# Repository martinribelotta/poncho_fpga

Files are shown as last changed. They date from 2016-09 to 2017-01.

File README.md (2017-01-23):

# FPGA Poncho para EDU CIAA

Poncho FPGA basado en la placa [Olimex iCE40HX1K-EVB](https://www.olimex.com/Products/FPGA/iCE40/iCE40HX1K-EVB/open-source-hardware)

> Licencia Apache 2.0 relicenciable a CIAA 1.0

## Caracteristicas
  - FPGA iCE40HX4K soportada por el proyecto IceStorm
  - 8-64MB de SDRAM
  - 64Mb SPI flash
  - Oscilador 50/100MHz on board
  - 52 I/O digitales 

## Lista de tareas
  - [x] Esqematico preeliminar
  - [x] Revision del esquematico
  - [x] Asignado de footprints
  - [x] Place and route
  - [x] Archivos de fabricacion
  - [x] Fabricación del PCB
  - [x] BOM (TBC)
  - [ ] Montaje y test

## Schematic
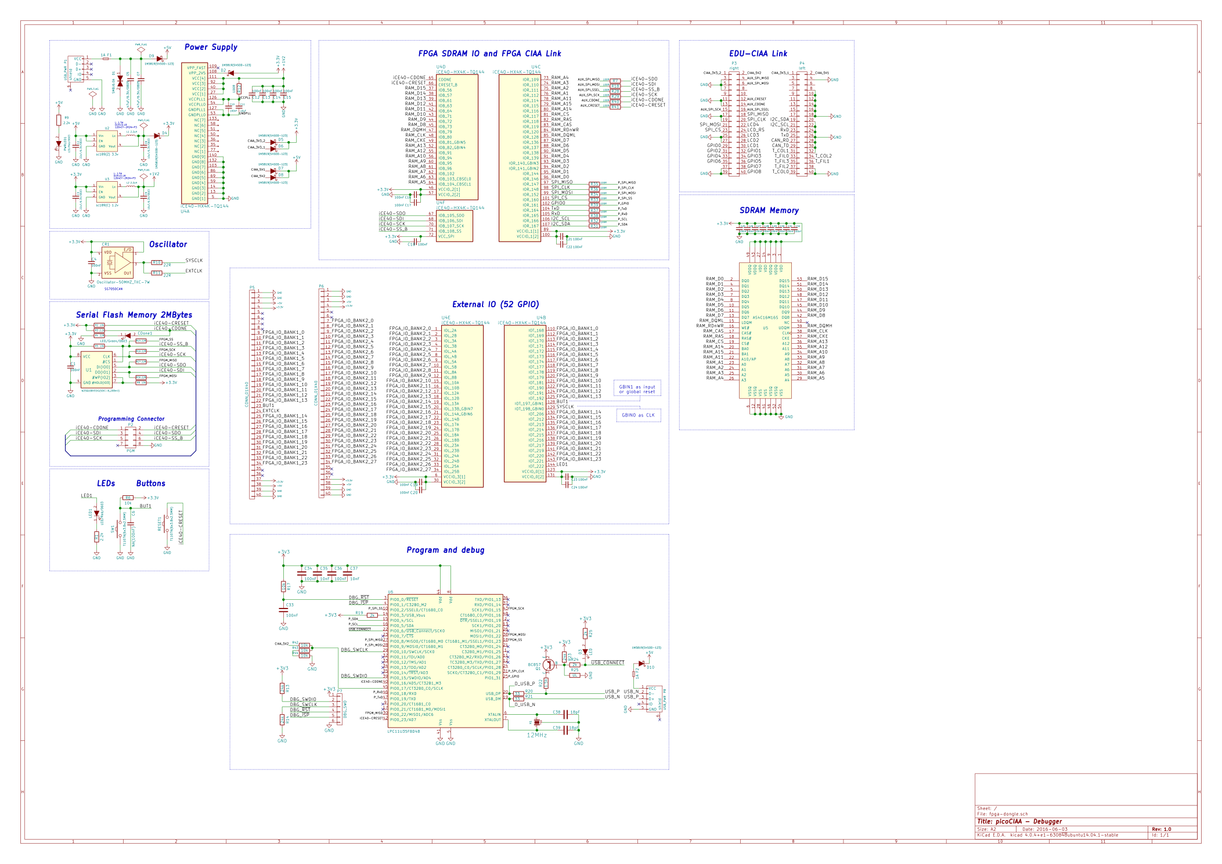
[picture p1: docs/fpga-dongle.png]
esquematico


## Board preview
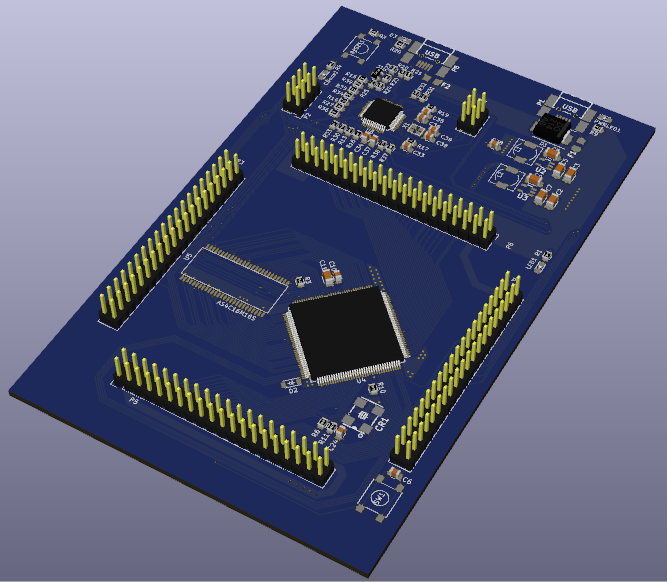
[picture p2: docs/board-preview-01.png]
preview1

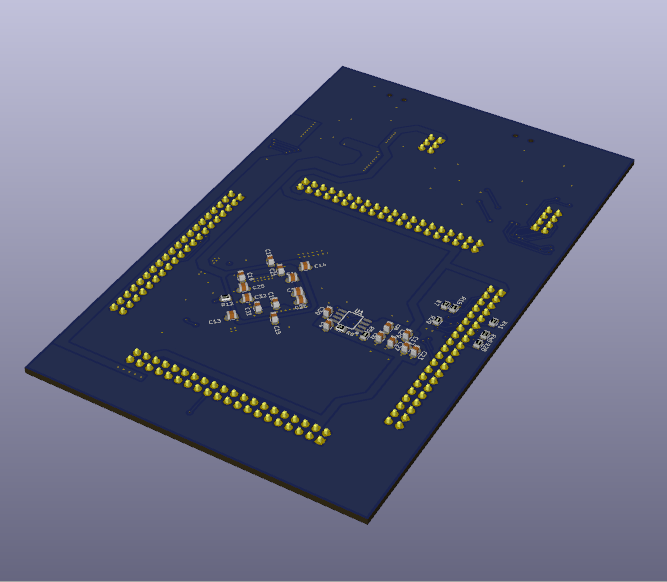
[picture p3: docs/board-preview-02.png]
preview2

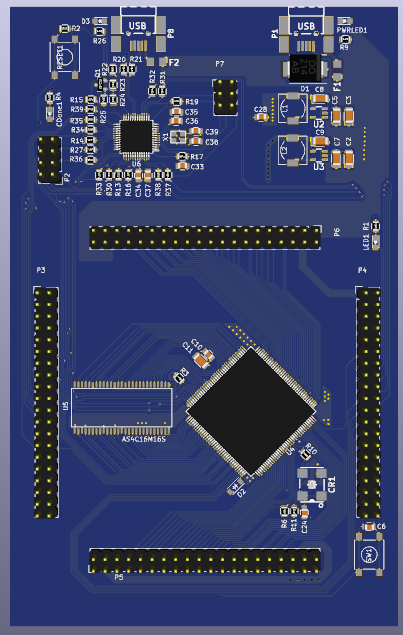
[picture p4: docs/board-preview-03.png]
preview3

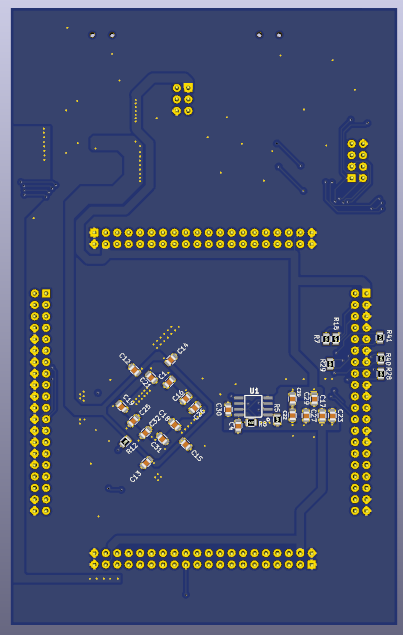
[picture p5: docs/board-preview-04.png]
preview4


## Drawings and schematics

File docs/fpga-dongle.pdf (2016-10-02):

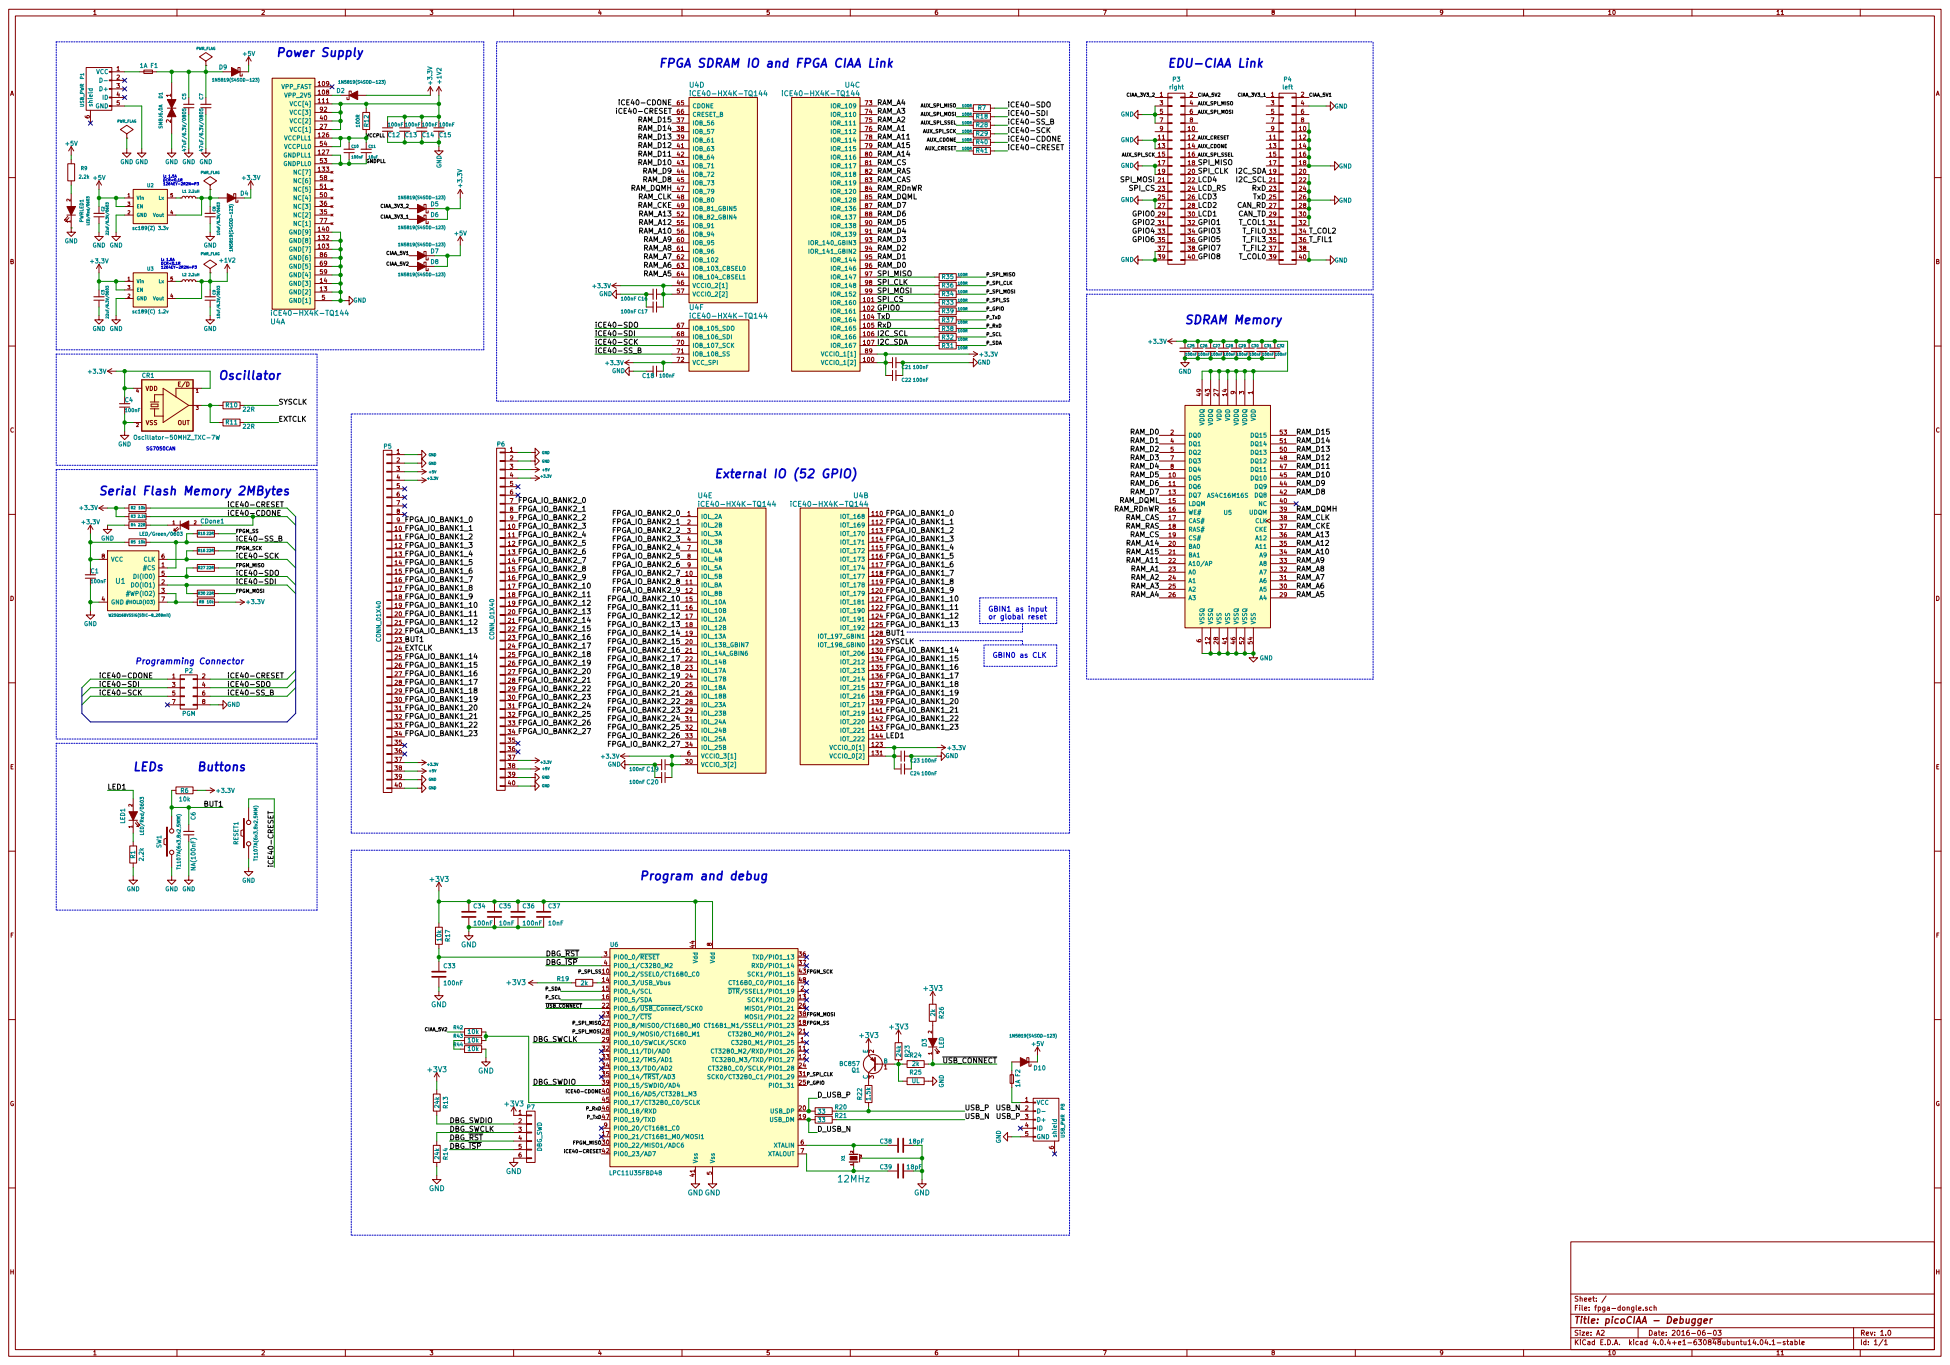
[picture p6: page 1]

File: fpga-dongle.sch Sheet: /
Id: 1/1 Title: picoCIAA - Debugger

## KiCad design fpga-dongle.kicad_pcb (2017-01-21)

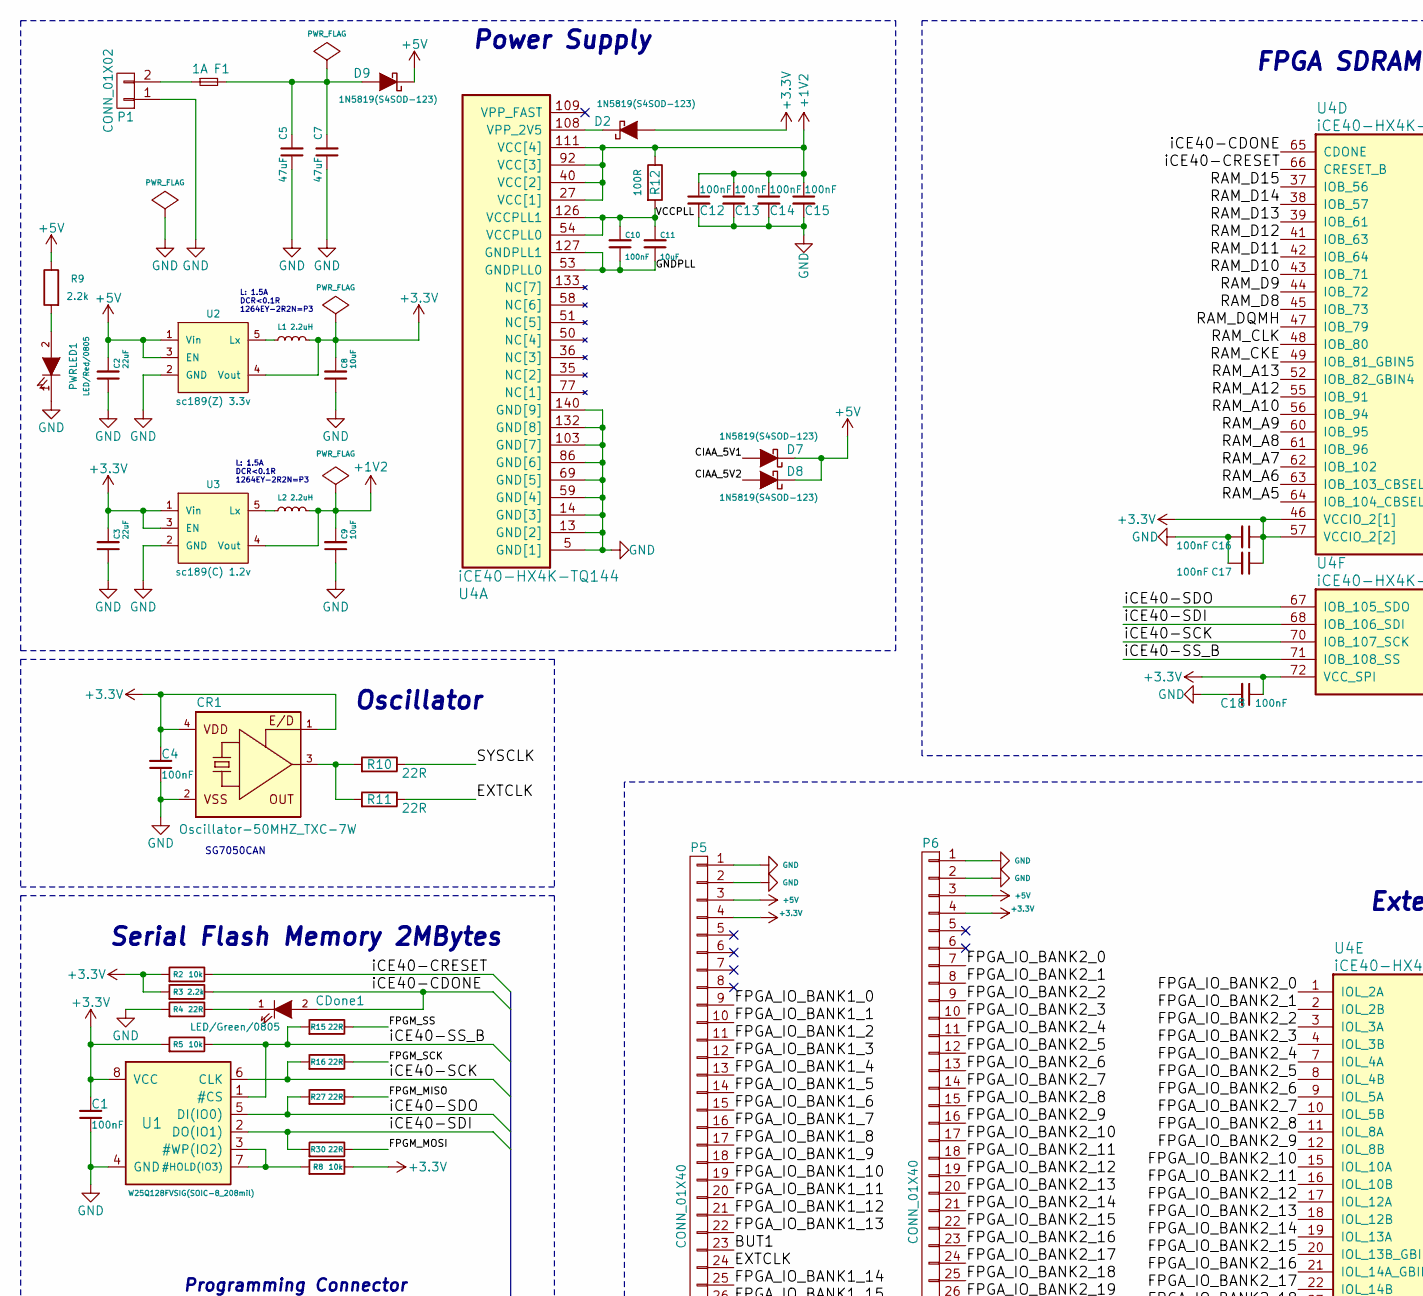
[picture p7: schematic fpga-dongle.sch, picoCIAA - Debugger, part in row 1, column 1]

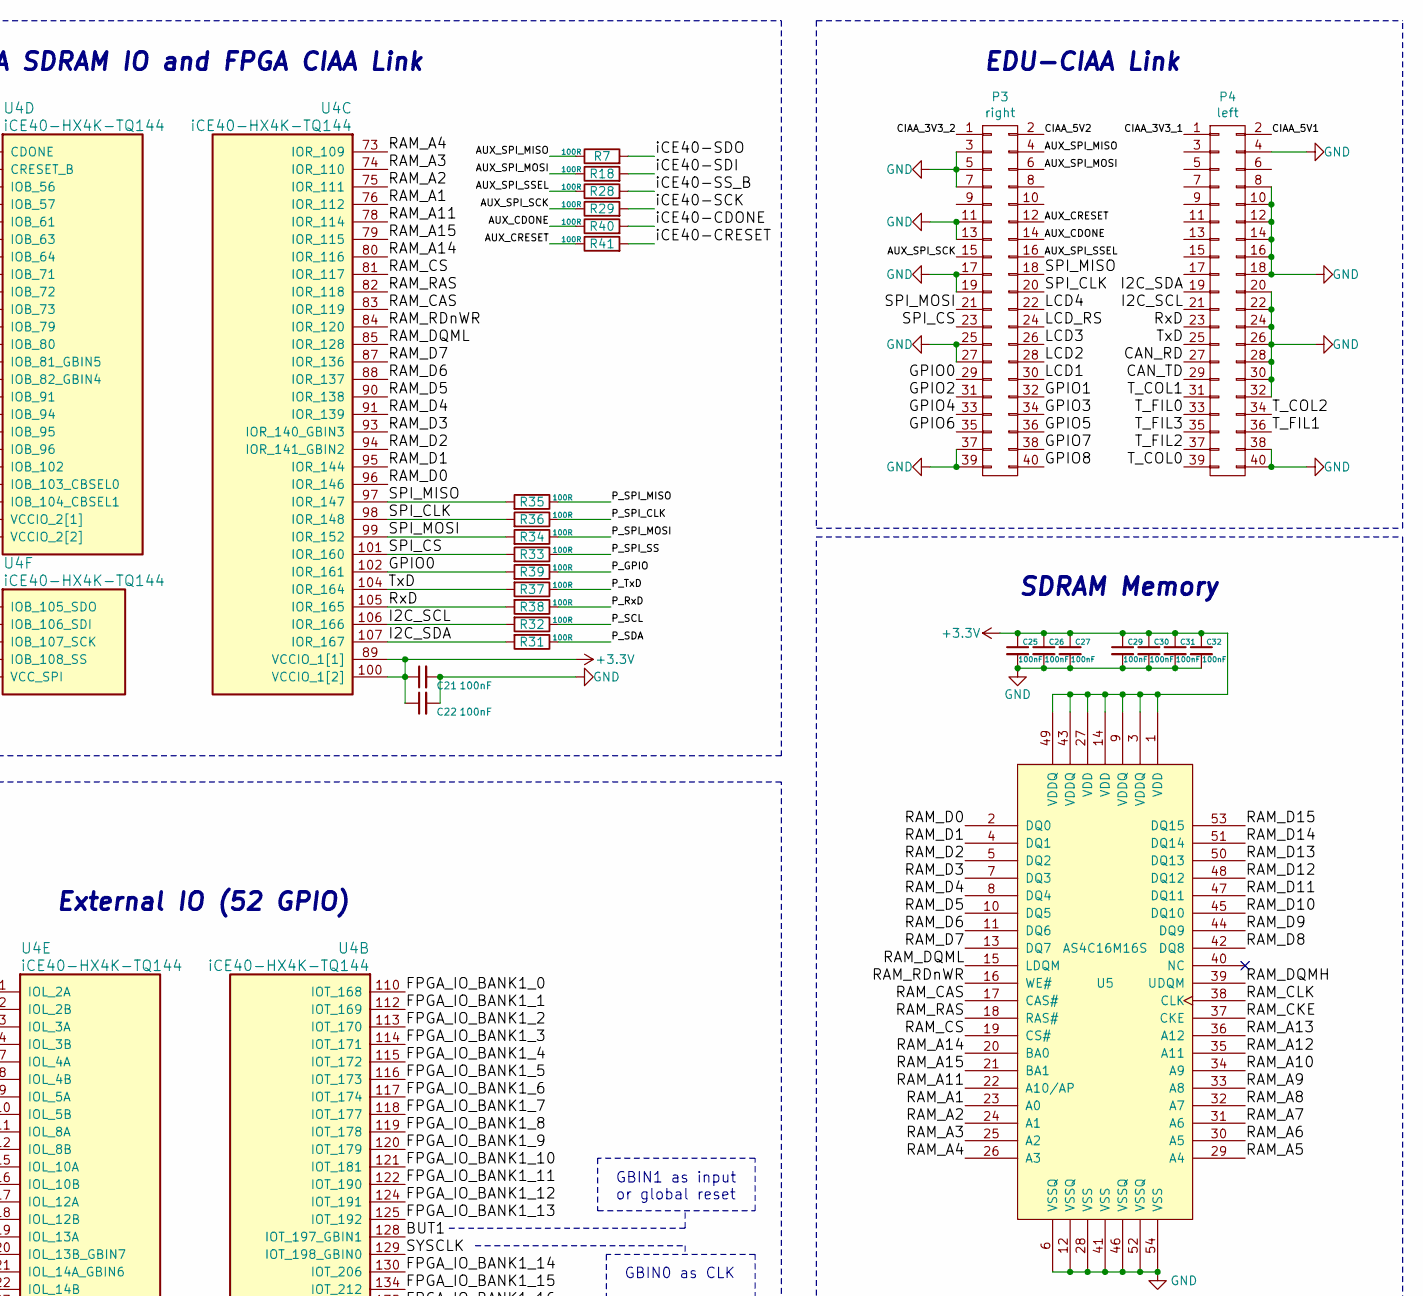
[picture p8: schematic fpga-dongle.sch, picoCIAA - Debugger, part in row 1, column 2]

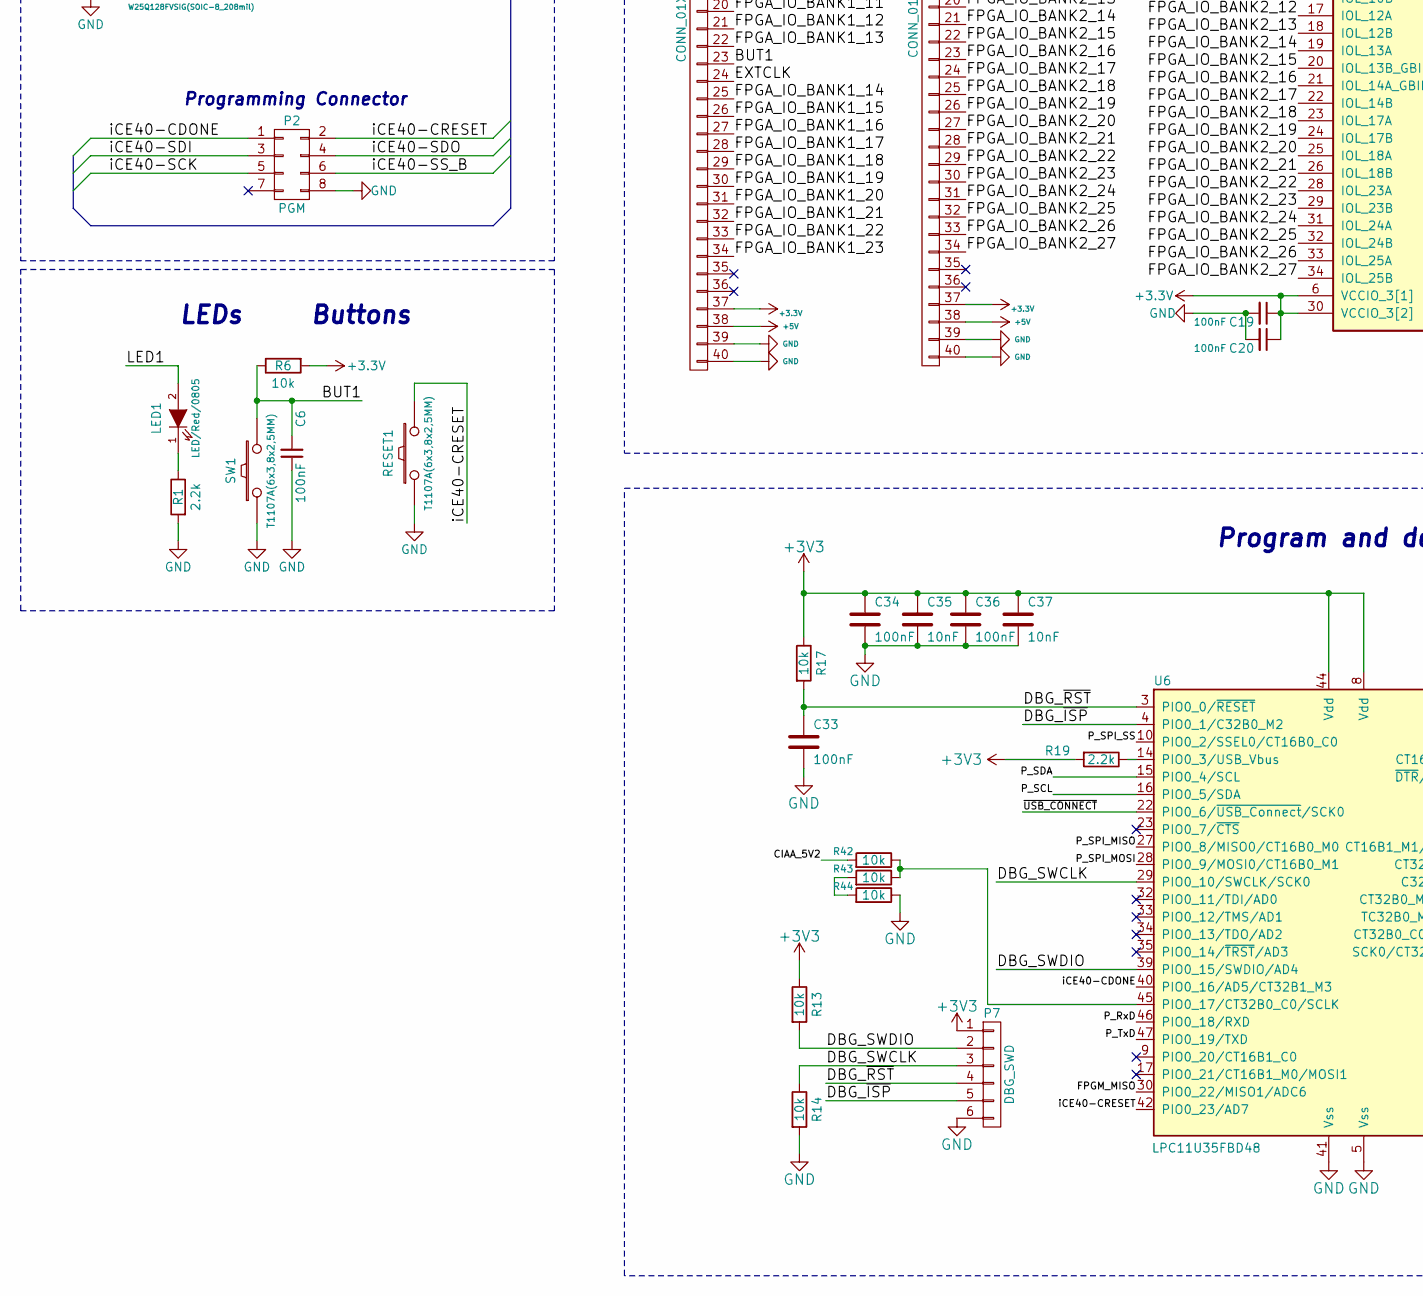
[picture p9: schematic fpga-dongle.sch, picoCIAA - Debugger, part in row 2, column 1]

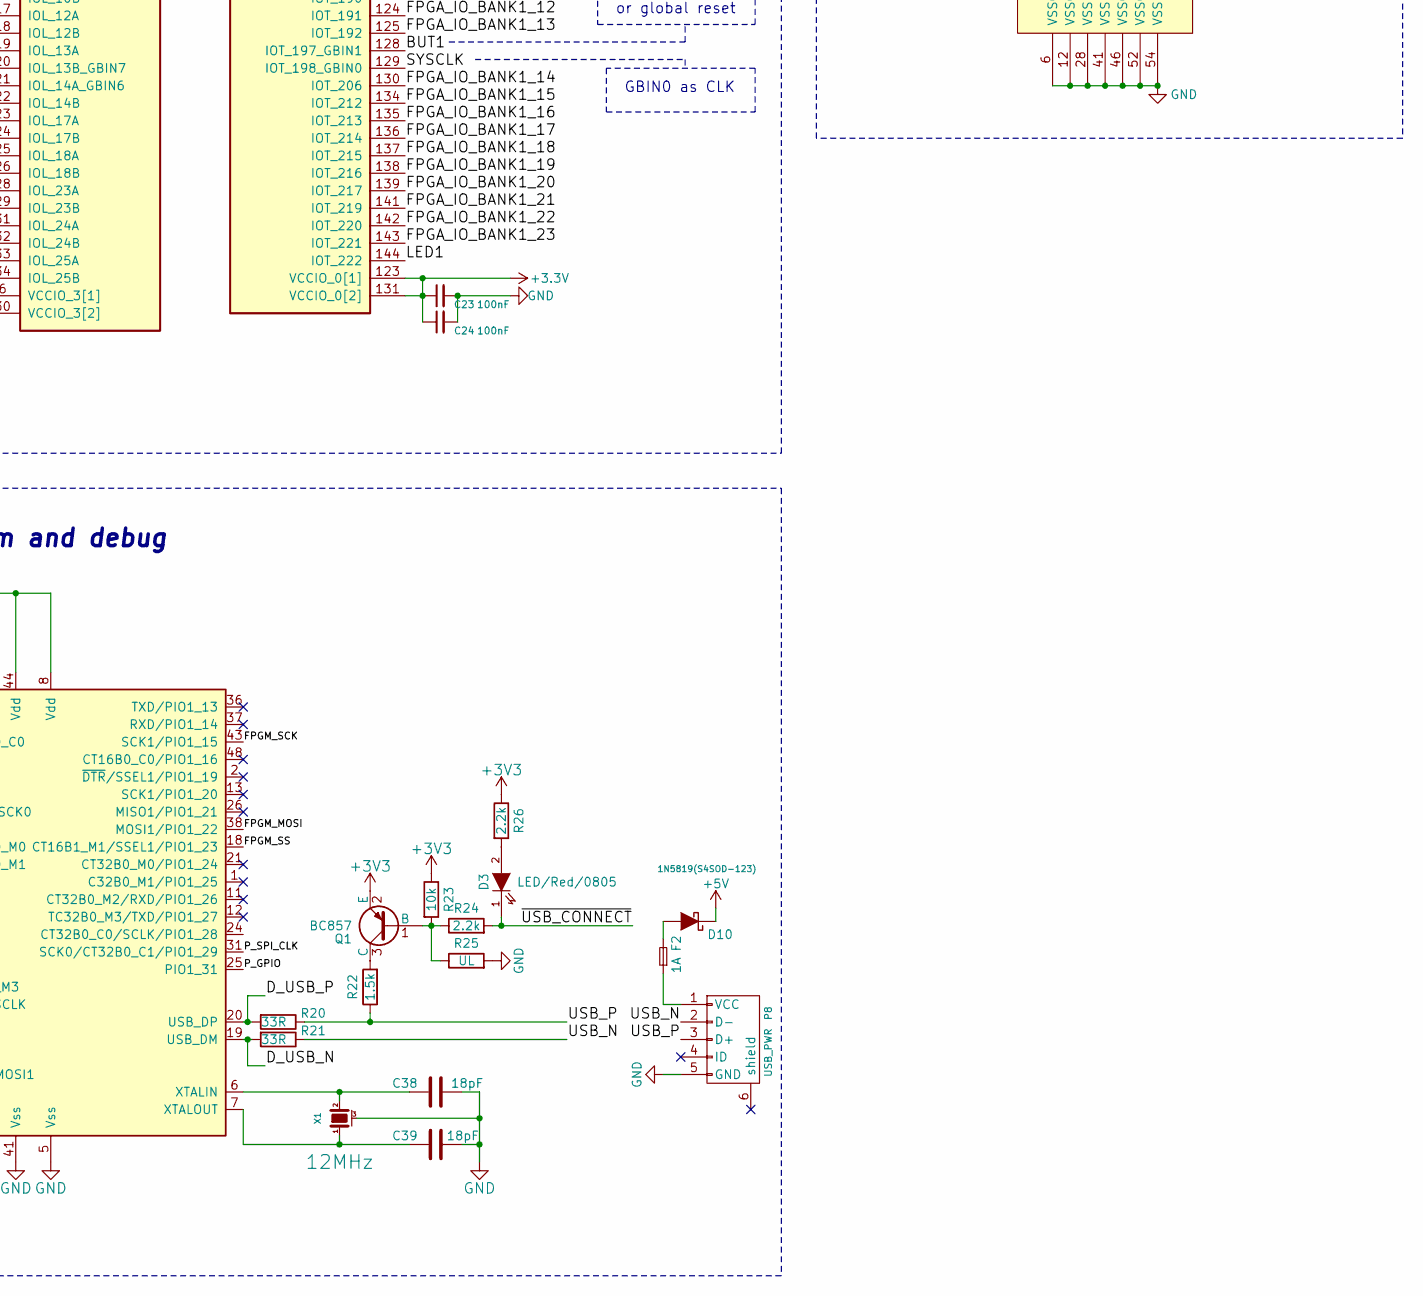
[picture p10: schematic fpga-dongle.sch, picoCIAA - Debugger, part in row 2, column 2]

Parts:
C1, C4, C6, C10, C12, C13, C14, C15, C16, C17, C18, C19, C20, C21, C22, C23, C24, C25, C26, C27, C29, C30, C31, C32, C33, C34, C36: 100nF; C_0805
C2, C3: 22uF; C_1206
C5, C7: 47uF; C_1206
C8, C9, C11: 10uF; C_1206
C35, C37: 10nF; C_0805
C38, C39: 18pF; C_0805
CDone1: LED/Green/0805; LED-0805
CR1: Oscillator-50MHZ_TXC-7W; Oscillator_7.0x5.0mm
D2, D7, D8, D9, D10: 1N5819(S4SOD-123); SOD-123
D3: LED/Red/0805; LED-0805
F1, F2: 1A; FUSE-1206
L1, L2: 2.2uH; Choke_SMD_6.3x6.3_H3
LED1: LED/Red/0805; LED-0805
P1: CONN_01X02; AK300-2
P2: PGM; Pin_Header_Straight_2x04
P3: right; Pin_Header_Straight_2x20
P4: left; Pin_Header_Straight_2x20
P5, P6: CONN_01X40; Pin_Header_Straight_2x20
P7: DBG_SWD; Pin_Header_Straight_2x03
P8: USB_PWR; USB_Mini-B-NOSILK
PWRLED1: LED/Red/0805; LED-0805
Q1: BC857; SOT-23
R1, R3, R9, R19, R24, R26: 2.2k; R_0805
R2, R5, R6, R8, R13, R14, R17, R23, R42, R43, R44: 10k; R_0805
R4, R10, R11, R15, R16, R27, R30: 22R; R_0805
R7, R12, R18, R28, R29, R31, R32, R33, R34, R35, R36, R37, R38, R39, R40, R41: 100R; R_0805
R20, R21: 33R; R_0805
R22: 1.5k; R_0805
R25: UL; R_0805
RESET1: T1107A(6x3,8x2,5MM); SW_SPST_PTS645
SW1: T1107A(6x3,8x2,5MM); SW_SPST_PTS645
U1: W25Q128FVSIG(SOIC-8_208mil); SOIC-8_208mil
U2: sc189(Z) 3.3v; SOT-23-5
U3: sc189(C) 1.2v; SOT-23-5
U4: iCE40-HX4K-TQ144; LQFP-144_20x20mm_Pitch0.5mm
U5: AS4C16M16S; TSOP_II_54
U6: LPC11U35FBD48; LQFP-48_7x7mm_Pitch0.5mm
X1: 12MHz; crystal_FA238-TSX3225; Digikey/Mouser 887-1831-1-ND

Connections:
+1V2: C9.2, C12.1, C13.1, C14.1, C15.1, L2.2, R12.1, U3.4 (Vout), U4.27 (VCC[1]), U4.40 (VCC[2]), U4.92 (VCC[3]), U4.111 (VCC[4])
+5V: C2.2, D7.1 (K), D8.1 (K), D9.1 (K), D10.1 (K), P5.3, P5.38, P6.3, P6.38, R9.1, U2.1 (Vin), U2.3 (EN)
/AUX_CDONE: P3.14, R40.1
/AUX_CRESET: P3.12, R41.1
/AUX_SPI_MISO: P3.4, R7.1
/AUX_SPI_MOSI: P3.6, R18.1
/AUX_SPI_SCK: P3.15, R29.1
/AUX_SPI_SSEL: P3.16, R28.1
/BUT1: C6.2, P5.23, R6.1, SW1.2, U4.128 (IOT_197_GBIN1)
/CAN_RD: P4.27
/CAN_TD: P4.29
/CIAA_3V3_1: P4.1
/CIAA_3V3_2: P3.1
/CIAA_5V1: D7.2 (A), P4.2
/CIAA_5V2: D8.2 (A), P3.2, R42.2
/DBG_SWCLK: P7.3, R14.1, U6.29 (PIO0_10/SWCLK/SCK0)
/DBG_SWDIO: P7.2, R13.2, U6.39 (PIO0_15/SWDIO/AD4)
/DBG_~ISP~: P7.5, U6.4 (PIO0_1/C32B0_M2)
/DBG_~RST~: C33.1, P7.4, R17.2, U6.3 (PIO0_0/~RESET)
/D_USB_N: R21.2, U6.19 (USB_DM)
/D_USB_P: R20.2, U6.20 (USB_DP)
/EXTCLK: P5.24, R11.1
/FPGA_IO_BANK1_0: P5.9, U4.110 (IOT_168)
/FPGA_IO_BANK1_1: P5.10, U4.112 (IOT_169)
/FPGA_IO_BANK1_2: P5.11, U4.113 (IOT_170)
/FPGA_IO_BANK1_3: P5.12, U4.114 (IOT_171)
/FPGA_IO_BANK1_4: P5.13, U4.115 (IOT_172)
/FPGA_IO_BANK1_5: P5.14, U4.116 (IOT_173)
/FPGA_IO_BANK1_6: P5.15, U4.117 (IOT_174)
/FPGA_IO_BANK1_7: P5.16, U4.118 (IOT_177)
/FPGA_IO_BANK1_8: P5.17, U4.119 (IOT_178)
/FPGA_IO_BANK1_9: P5.18, U4.120 (IOT_179)
/FPGA_IO_BANK1_10: P5.19, U4.121 (IOT_181)
/FPGA_IO_BANK1_11: P5.20, U4.122 (IOT_190)
/FPGA_IO_BANK1_12: P5.21, U4.124 (IOT_191)
/FPGA_IO_BANK1_13: P5.22, U4.125 (IOT_192)
/FPGA_IO_BANK1_14: P5.25, U4.130 (IOT_206)
/FPGA_IO_BANK1_15: P5.26, U4.134 (IOT_212)
/FPGA_IO_BANK1_16: P5.27, U4.135 (IOT_213)
/FPGA_IO_BANK1_17: P5.28, U4.136 (IOT_214)
/FPGA_IO_BANK1_18: P5.29, U4.137 (IOT_215)
/FPGA_IO_BANK1_19: P5.30, U4.138 (IOT_216)
/FPGA_IO_BANK1_20: P5.31, U4.139 (IOT_217)
/FPGA_IO_BANK1_21: P5.32, U4.141 (IOT_219)
/FPGA_IO_BANK1_22: P5.33, U4.142 (IOT_220)
/FPGA_IO_BANK1_23: P5.34, U4.143 (IOT_221)
/FPGA_IO_BANK2_0: P6.7, U4.1 (IOL_2A)
/FPGA_IO_BANK2_1: P6.8, U4.2 (IOL_2B)
/FPGA_IO_BANK2_2: P6.9, U4.3 (IOL_3A)
/FPGA_IO_BANK2_3: P6.10, U4.4 (IOL_3B)
/FPGA_IO_BANK2_4: P6.11, U4.7 (IOL_4A)
/FPGA_IO_BANK2_5: P6.12, U4.8 (IOL_4B)
/FPGA_IO_BANK2_6: P6.13, U4.9 (IOL_5A)
/FPGA_IO_BANK2_7: P6.14, U4.10 (IOL_5B)
/FPGA_IO_BANK2_8: P6.15, U4.11 (IOL_8A)
/FPGA_IO_BANK2_9: P6.16, U4.12 (IOL_8B)
/FPGA_IO_BANK2_10: P6.17, U4.15 (IOL_10A)
/FPGA_IO_BANK2_11: P6.18, U4.16 (IOL_10B)
/FPGA_IO_BANK2_12: P6.19, U4.17 (IOL_12A)
/FPGA_IO_BANK2_13: P6.20, U4.18 (IOL_12B)
/FPGA_IO_BANK2_14: P6.21, U4.19 (IOL_13A)
/FPGA_IO_BANK2_15: P6.22, U4.20 (IOL_13B_GBIN7)
/FPGA_IO_BANK2_16: P6.23, U4.21 (IOL_14A_GBIN6)
/FPGA_IO_BANK2_17: P6.24, U4.22 (IOL_14B)
/FPGA_IO_BANK2_18: P6.25, U4.23 (IOL_17A)
/FPGA_IO_BANK2_19: P6.26, U4.24 (IOL_17B)
/FPGA_IO_BANK2_20: P6.27, U4.25 (IOL_18A)
/FPGA_IO_BANK2_21: P6.28, U4.26 (IOL_18B)
/FPGA_IO_BANK2_22: P6.29, U4.28 (IOL_23A)
/FPGA_IO_BANK2_23: P6.30, U4.29 (IOL_23B)
/FPGA_IO_BANK2_24: P6.31, U4.31 (IOL_24A)
/FPGA_IO_BANK2_25: P6.32, U4.32 (IOL_24B)
/FPGA_IO_BANK2_26: P6.33, U4.33 (IOL_25A)
/FPGA_IO_BANK2_27: P6.34, U4.34 (IOL_25B)
/FPGM_MISO: R27.1, U6.30 (PIO0_22/MISO1/ADC6)
/FPGM_MOSI: R30.1, U6.38 (MOSI1/PIO1_22)
/FPGM_SCK: R16.1, U6.43 (SCK1/PIO1_15)
/FPGM_SS: R15.1, U6.18 (CT16B1_M1/SSEL1/PIO1_23)
/GNDPLL: C10.1, C11.1, U4.53 (GNDPLL0), U4.127 (GNDPLL1)
/GPIO0: P3.29, R39.2, U4.102 (IOR_161)
/GPIO1: P3.32
/GPIO2: P3.31
/GPIO3: P3.34
/GPIO4: P3.33
/GPIO5: P3.36
/GPIO6: P3.35
/GPIO7: P3.38
/GPIO8: P3.40
/I2C_SCL: P4.21, R32.2, U4.106 (IOR_166)
/I2C_SDA: P4.19, R31.2, U4.107 (IOR_167)
/LCD1: P3.30
/LCD2: P3.28
/LCD3: P3.26
/LCD4: P3.22
/LCD_RS: P3.24
/LED1: LED1.2 (A), U4.144 (IOT_222)
/P_GPIO: R39.1, U6.25 (PIO1_31)
/P_RxD: R38.1, U6.46 (PIO0_18/RXD)
/P_SCL: R32.1, U6.16 (PIO0_5/SDA)
/P_SDA: R31.1, U6.15 (PIO0_4/SCL)
/P_SPI_CLK: R36.1, U6.31 (SCK0/CT32B0_C1/PIO1_29)
/P_SPI_MISO: R35.1, U6.27 (PIO0_8/MISO0/CT16B0_M0)
/P_SPI_MOSI: R34.1, U6.28 (PIO0_9/MOSI0/CT16B0_M1)
/P_SPI_SS: R33.1, U6.10 (PIO0_2/SSEL0/CT16B0_C0)
/P_TxD: R37.1, U6.47 (PIO0_19/TXD)
/RAM_A1: U4.76 (IOR_112), U5.23 (A0)
/RAM_A2: U4.75 (IOR_111), U5.24 (A1)
/RAM_A3: U4.74 (IOR_110), U5.25 (A2)
/RAM_A4: U4.73 (IOR_109), U5.26 (A3)
/RAM_A5: U4.64 (IOB_104_CBSEL1), U5.29 (A4)
/RAM_A6: U4.63 (IOB_103_CBSEL0), U5.30 (A5)
/RAM_A7: U4.62 (IOB_102), U5.31 (A6)
/RAM_A8: U4.61 (IOB_96), U5.32 (A7)
/RAM_A9: U4.60 (IOB_95), U5.33 (A8)
/RAM_A10: U4.56 (IOB_94), U5.34 (A9)
/RAM_A11: U4.78 (IOR_114), U5.22 (A10/AP)
/RAM_A12: U4.55 (IOB_91), U5.35 (A11)
/RAM_A13: U4.52 (IOB_82_GBIN4), U5.36 (A12)
/RAM_A14: U4.80 (IOR_116), U5.20 (BA0)
/RAM_A15: U4.79 (IOR_115), U5.21 (BA1)
/RAM_CAS: U4.83 (IOR_119), U5.17 (CAS#)
/RAM_CKE: U4.49 (IOB_81_GBIN5), U5.37 (CKE)
/RAM_CLK: U4.48 (IOB_80), U5.38 (CLK)
/RAM_CS: U4.81 (IOR_117), U5.19 (CS#)
/RAM_D0: U4.96 (IOR_146), U5.2 (DQ0)
/RAM_D1: U4.95 (IOR_144), U5.4 (DQ1)
/RAM_D2: U4.94 (IOR_141_GBIN2), U5.5 (DQ2)
/RAM_D3: U4.93 (IOR_140_GBIN3), U5.7 (DQ3)
/RAM_D4: U4.91 (IOR_139), U5.8 (DQ4)
/RAM_D5: U4.90 (IOR_138), U5.10 (DQ5)
/RAM_D6: U4.88 (IOR_137), U5.11 (DQ6)
/RAM_D7: U4.87 (IOR_136), U5.13 (DQ7)
/RAM_D8: U4.45 (IOB_73), U5.42 (DQ8)
/RAM_D9: U4.44 (IOB_72), U5.44 (DQ9)
/RAM_D10: U4.43 (IOB_71), U5.45 (DQ10)
/RAM_D11: U4.42 (IOB_64), U5.47 (DQ11)
/RAM_D12: U4.41 (IOB_63), U5.48 (DQ12)
/RAM_D13: U4.39 (IOB_61), U5.50 (DQ13)
/RAM_D14: U4.38 (IOB_57), U5.51 (DQ14)
/RAM_D15: U4.37 (IOB_56), U5.53 (DQ15)
/RAM_DQMH: U4.47 (IOB_79), U5.39 (UDQM)
/RAM_DQML: U4.85 (IOR_128), U5.15 (LDQM)
/RAM_RAS: U4.82 (IOR_118), U5.18 (RAS#)
/RAM_RDnWR: U4.84 (IOR_120), U5.16 (WE#)
/RxD: P4.23, R38.2, U4.105 (IOR_165)
/SPI_CLK: P3.20, R36.2, U4.98 (IOR_148)
/SPI_CS: P3.23, R33.2, U4.101 (IOR_160)
/SPI_MISO: P3.18, R35.2, U4.97 (IOR_147)
/SPI_MOSI: P3.21, R34.2, U4.99 (IOR_152)
/SYSCLK: R10.1, U4.129 (IOT_198_GBIN0)
/T_COL0: P4.39
/T_COL1: P4.31
/T_COL2: P4.34
/T_FIL0: P4.33
/T_FIL1: P4.36
/T_FIL2: P4.37
/T_FIL3: P4.35
/TxD: P4.25, R37.2, U4.104 (IOR_164)
/USB_N: P8.2 (D-), R21.1
/USB_P: P8.3 (D+), R20.1, R22.1
/VCCPLL: C10.2, C11.2, R12.2, U4.54 (VCCPLL0), U4.126 (VCCPLL1)
/iCE40-CDONE: CDone1.2 (A), P2.1, R3.1, R40.2, U4.65 (CDONE), U6.40 (PIO0_16/AD5/CT32B1_M3)
/iCE40-CRESET: P2.2, R2.1, R41.2, RESET1.2, U4.66 (CRESET_B), U6.42 (PIO0_23/AD7)
/iCE40-SCK: P2.5, R16.2, R29.2, U1.6 (CLK), U4.70 (IOB_107_SCK)
/iCE40-SDI: P2.3, R18.2, R30.2, U1.2 (DO(IO1)), U4.68 (IOB_106_SDI)
/iCE40-SDO: P2.4, R7.2, R27.2, U1.5 (DI(IO0)), U4.67 (IOB_105_SDO)
/iCE40-SS_B: P2.6, R5.1, R15.2, R28.2, U1.1 (#CS), U4.71 (IOB_108_SS)
/~USB_CONNECT~: D3.1 (K), R24.2, U6.22 (PIO0_6/~USB_Connect~/SCK0)
GND: C1.1, C2.1, C3.1, C4.1, C5.1, C6.1, C7.1, C8.1, C9.1, C12.2, C13.2, C14.2, C15.2, C16.2, C17.2, C18.2, C19.2, C20.2, C21.2, C22.2, C23.2, C24.2, C25.2, C26.2, C27.2, C29.2, C30.2, C31.2, C32.2, C33.2, C34.2, C35.2, C36.2, C37.2, C38.2, C39.2, CR1.2 (VSS), P1.1, P2.8, P3.3, P3.5, P3.7, P3.11, P3.13, P3.17, P3.19, P3.25, P3.27, P3.37, P3.39, P4.4, P4.8, P4.10, P4.12, P4.14, P4.16, P4.18, P4.20, P4.22, P4.24, P4.26, P4.28, P4.30, P4.32, P4.38, P4.40, P5.1, P5.2, P5.39, P5.40, P6.1, P6.2, P6.39, P6.40, P7.6, P8.5 (GND), PWRLED1.1 (K), R1.2, R4.2, R14.2, R25.2, R44.1, RESET1.1, SW1.1, U1.4 (GND), U2.2 (GND), U3.2 (GND), U4.5 (GND[1]), U4.13 (GND[2]), U4.14 (GND[3]), U4.59 (GND[4]), U4.69 (GND[5]), U4.86 (GND[6]), U4.103 (GND[7]), U4.132 (GND[8]), U4.140 (GND[9]), U5.6 (VSSQ), U5.12 (VSSQ), U5.28 (VSS), U5.41 (VSS), U5.46 (VSSQ), U5.52 (VSSQ), U5.54 (VSS), U6.5 (Vss), U6.41 (Vss), X1.3 (case)
unnamed: C5.2, C7.2, D9.2 (A), F1.2
unnamed: C38.1, U6.6 (XTALIN), X1.2
unnamed: C39.1, U6.7 (XTALOUT), X1.1
unnamed: CDone1.1 (K), R4.1
unnamed: CR1.3 (OUT), R10.2, R11.2
unnamed: D2.1 (K), U4.108 (VPP_2V5)
unnamed: D3.2 (A), R26.2
unnamed: D10.2 (A), F2.2
unnamed: F1.1, P1.2
unnamed: F2.1, P8.1 (VCC)
unnamed: L1.1, U2.5 (Lx)
unnamed: L2.1, U3.5 (Lx)
unnamed: LED1.1 (K), R1.1
unnamed: PWRLED1.2 (A), R9.2
unnamed: Q1.1 (B), R23.2, R24.1, R25.1
unnamed: Q1.3 (C), R22.2
unnamed: R8.2, U1.3 (#WP(IO2)), U1.7 (#HOLD(IO3))
unnamed: R19.1, U6.14 (PIO0_3/USB_Vbus)
unnamed: R42.1, R43.1, U6.45 (PIO0_17/CT32B0_C0/SCLK)
unnamed: R43.2, R44.2

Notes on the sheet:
Power Supply
Oscillator
Serial Flash Memory 2MBytes
Programming Connector
LEDs
Buttons
EDU-CIAA Link
SDRAM Memory
FPGA SDRAM IO and FPGA CIAA Link
External IO (52 GPIO)
GBIN0 as CLK
GBIN1 as input or global reset
L: 1.5A DCR<0.1R 1264EY-2R2N=P3
SG7050CAN
Program and debug

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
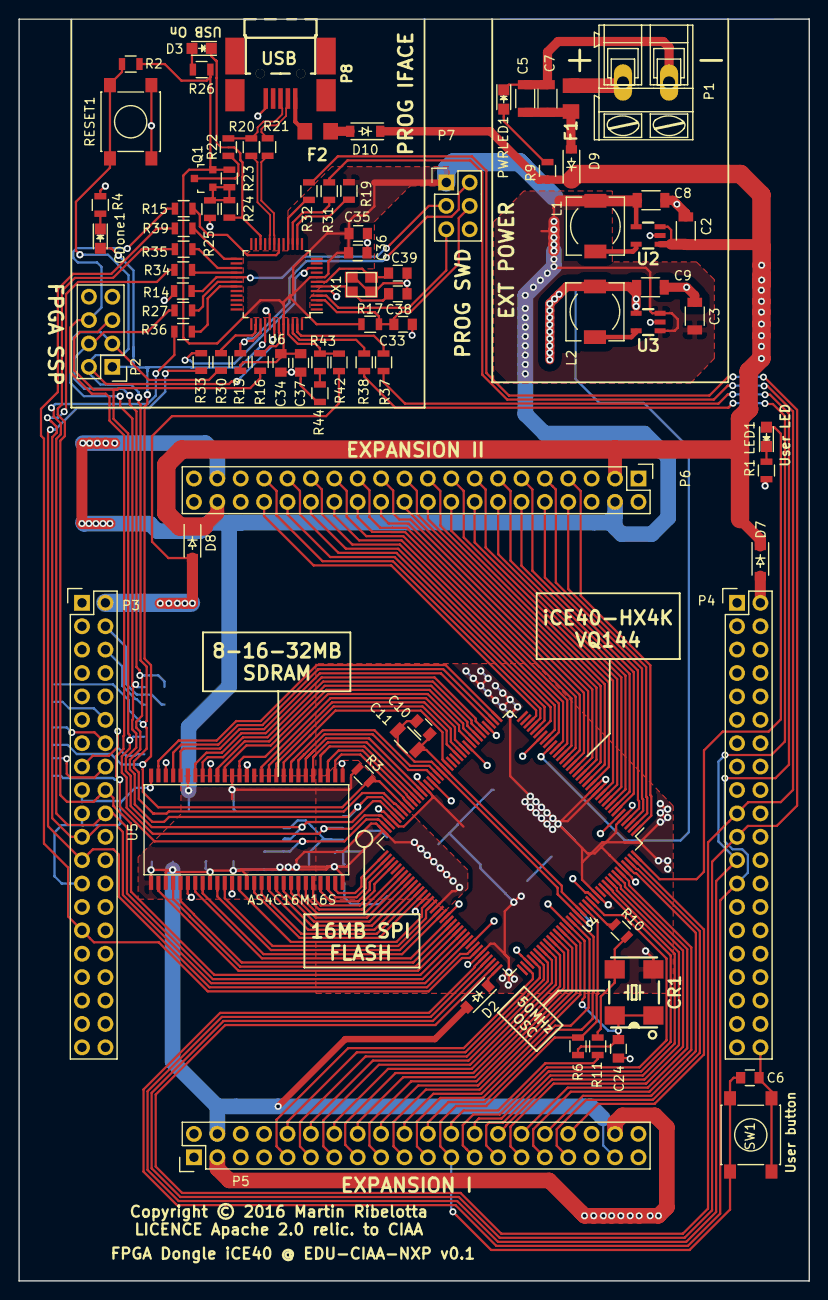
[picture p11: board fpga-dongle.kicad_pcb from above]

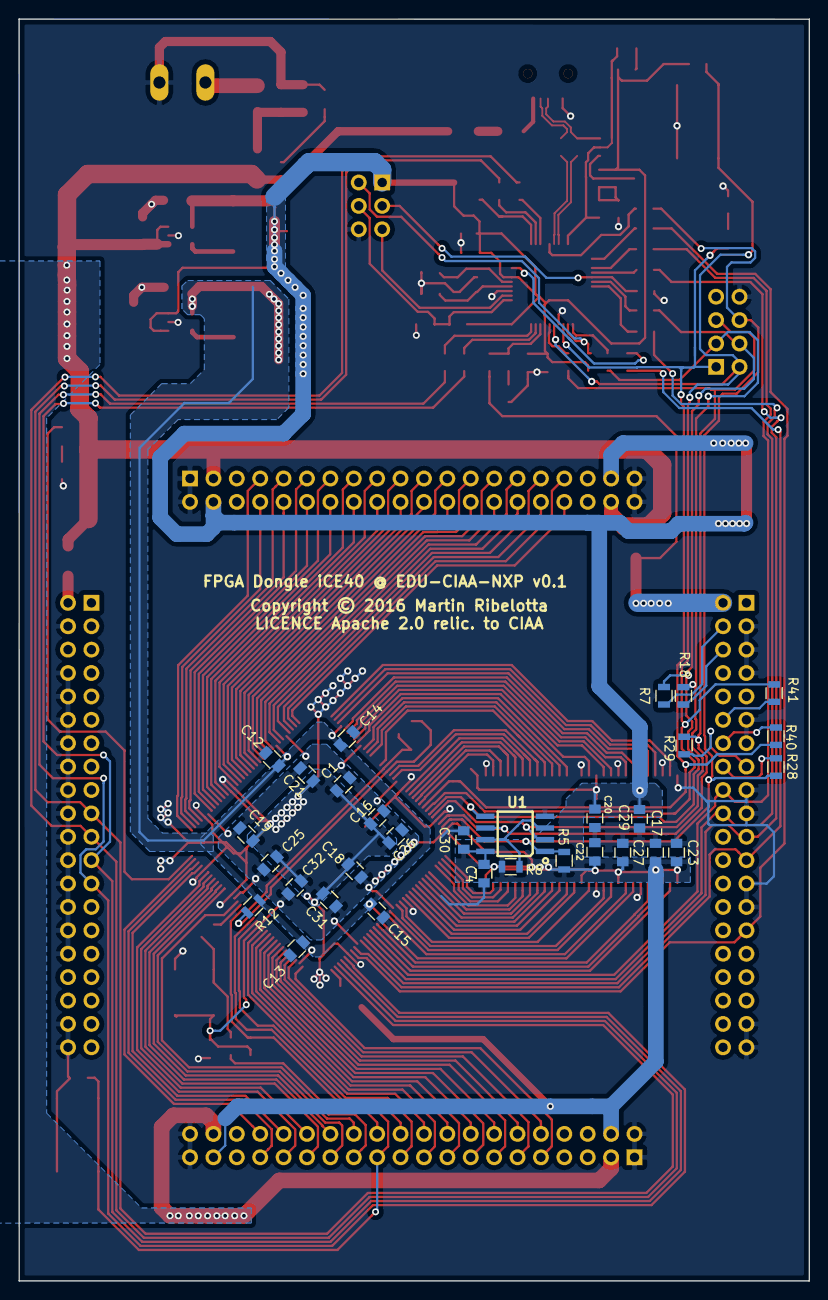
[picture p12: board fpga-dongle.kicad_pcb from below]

Board: 2 copper layers, 85.8 x 137.0 mm, 114 parts (31 on the bottom side), 166 nets.

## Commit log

2016-07-24 Assigned componets, first partial place
    [fpga-dongle.kicad_pcb, fpga-dongle.sch]
2016-09-12 First 144LQFP version. To be revised
    [fpga-dongle.kicad_pcb, fpga-dongle.sch]
2016-09-13 First component assign and preeliminar place
    [fpga-dongle.kicad_pcb, fpga-dongle.sch]
2016-09-20 Added SPI programmer with LPC11U35 as MSC
    [fpga-dongle.kicad_pcb, fpga-dongle.sch]
2016-09-20 Update schematics and coumentation
2016-09-23 Reroute SDRAM, connect to EDU-CIAA conenctor, fix schematic net tames
    [fpga-dongle.kicad_pcb, fpga-dongle.sch]
2016-09-24 More route (PWR net connectors TODO)
    [fpga-dongle.kicad_pcb]
2016-09-24 First DRC pass. Remain unconenct some 3v3 and 5v
    [fpga-dongle.kicad_pcb]
2016-09-25 Fix CIAA connector side error, power net route
    [fpga-dongle.kicad_pcb, fpga-dongle.sch]
2016-09-26 Fix CIAA connector side. Reroute bad lines. First DRC of PCB
    [fpga-dongle.kicad_pcb, fpga-dongle.sch]
2016-09-26 Update docs, create board preview images
2016-09-29 Fix 2V5 net diode from 1v2 to 3v3
    [fpga-dongle.kicad_pcb, fpga-dongle.sch]
2016-10-02 Add miltiple power source handling, reroute pertinent nets
    [fpga-dongle.kicad_pcb, fpga-dongle.sch]
2016-10-07 Change USB power-only connector by screw connector
    [fpga-dongle.kicad_pcb, fpga-dongle.sch]
2016-10-07 PCB annotations
    [fpga-dongle.kicad_pcb]
2016-10-07 Partial rework of changes lost in last conflict
    [fpga-dongle.kicad_pcb, fpga-dongle.sch]
2016-10-09 More PCB annotations, some rework on GND plane
    [fpga-dongle.kicad_pcb, fpga-dongle.sch]
2016-10-15 Copyright label on board
    [fpga-dongle.kicad_pcb]
2016-10-15 Copyright info on bottom sylkscreen
    [fpga-dongle.kicad_pcb]
2016-10-19 Correct SDRAM footprint, add mounting joles, first gerber for cuotation
    [fpga-dongle-B.Cu.gbl, fpga-dongle-B.Mask.gbs, fpga-dongle-B.Paste.gbp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]
2016-10-30 Add Edge cut to gerbers
    [fpga-dongle-B.Cu.gbl, fpga-dongle-B.Mask.gbs, fpga-dongle-B.Paste.gbp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]
2016-11-08 Verified gerbers from OurPCB
    [fpga-dongle-B.Cu.gbl, fpga-dongle-B.Mask.gbs, fpga-dongle-B.Paste.gbp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]
2017-01-21 Remove unnecesary components and clean power supply
    [fpga-dongle.kicad_pcb, fpga-dongle.sch]

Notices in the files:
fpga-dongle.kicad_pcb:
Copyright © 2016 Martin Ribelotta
